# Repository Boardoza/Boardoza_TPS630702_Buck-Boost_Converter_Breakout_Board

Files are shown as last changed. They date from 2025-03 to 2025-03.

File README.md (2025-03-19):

# Boardoza TPS630702 Buck-Boost Regulator Module

The TPS630702 Buck-Boost Converter Breakout Board is an efficient, compact power management solution for applications requiring stable voltage output over a wide input voltage range. This module features automatic transition between step-down and boost mode, making it ideal for battery-powered projects. With high efficiency of up to 95%, adjustable output voltage selection, and multiple safety protections, it provides a reliable power supply for embedded systems, IoT devices, and other electronics requiring regulated power.

## [Click here to purchase!](https://www.ozdisan.com/maker-ve-iot-urunleri/boardoza/boardoza-modulleri/BOARDOZA-TPS630702/1206511)

|Front Side|Back Side|
|:---:|:---:|
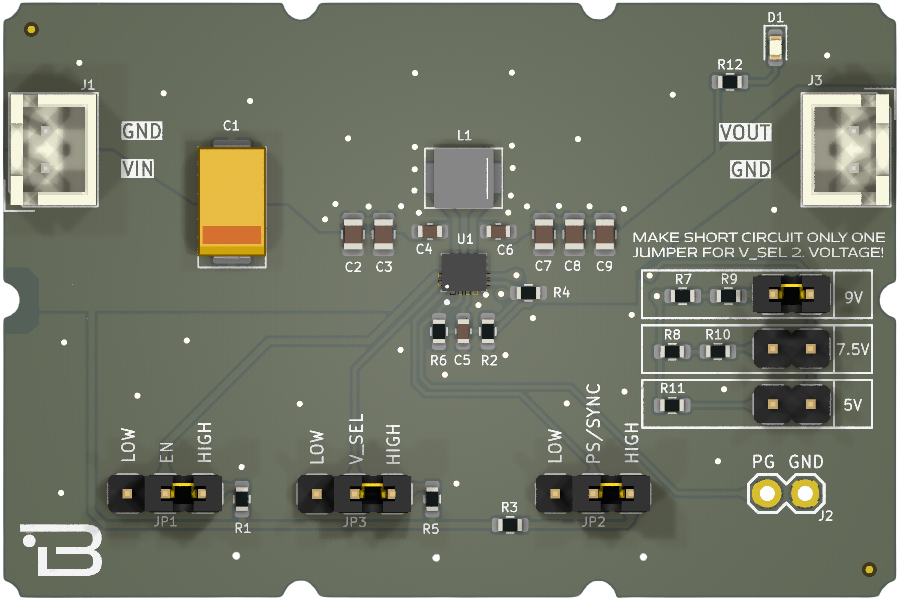
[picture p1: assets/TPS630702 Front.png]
Front
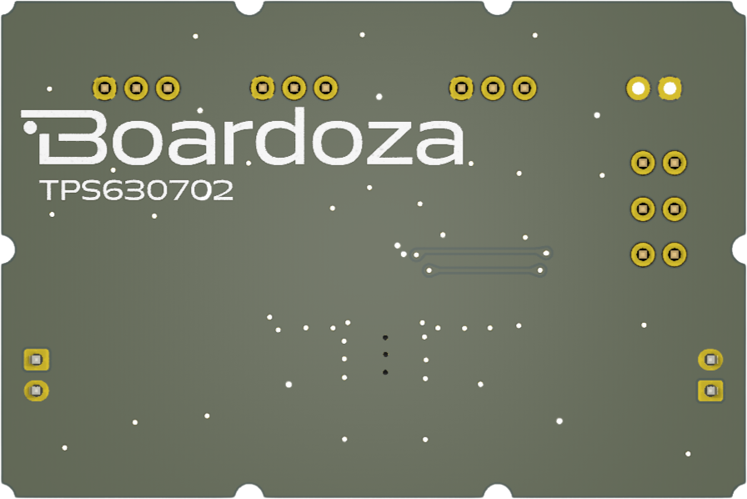
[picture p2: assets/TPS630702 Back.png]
Back
| | |

---

## Key Features

- **Wide Input Voltage Range**: Operates from 2.0V to 16V, suitable for battery and adapter applications.
- **Selectable Output Voltage**: Provides 3.3V by default, with options for 5V, 7.5V, and 9V via jumper selection.
- **High Current Capability**: Supports up to **2A output in both Buck and Boost modes**.
- **Automatic Buck-Boost Transition**: Seamlessly switches between step-down and boost mode depending on input voltage.
- **Load Disconnect & Output Discharge**: Ensures safety during shutdown.
- **Efficiency**: Up to 95%, reducing heat dissipation and improving battery life.
- **Protection Features**: Includes input/output overvoltage protection and undervoltage lockout.

---

## Technical Specifications

**Input Voltage:** 2.0V - 16V  

**Input Voltage Type:** Molex 2-pin 2.50mm header  

**Functions:** Buck-Boost Voltage Regulator  

**Output Voltage:** 3.3V, 5V, 7.5V, 9V (Selectable)  

**Output Current:**

- **Buck Mode:** 2A
- **Boost Mode:** 2A (VIN = 4V, VOUT = 5V)  

**Efficiency:** Up to **95%**  

**Operating Temperature:** -40°C ~ +150°C  

**Board Dimensions:** 40mm x 60mm  

---

## **Board Pinout**

### **J1 - Power Input Connector**

| Pin Number | Pin Name | Description |
|:---:|:---:|---|
| 1 | VIN | Voltage Input Pin (2V - 16V) |
| 2 | GND | Ground |

### **J2 - Power Good (PG) Indicator**

| Pin Number | Pin Name | Description |
|:---:|:---:|---|
| 1 | PG | Power Good signal, indicating output voltage status. |
| 2 | GND | Ground |

### **J3 - Output Connector**

| Pin Number | Pin Name | Description |
|:---:|:---:|---|
| 1 | VOUT | Adjustable Buck-Boost output (3.3V - 5V - 7.5V - 9V) |
| 2 | GND | Ground |

### **JP1 - Enable Control**

| Pin Number | Pin Name | Description |
|:---:|:---:|---|
| 1 | LOW | Connect to GND |
| 2 | EN | Regulator Enable Pin (Default: HIGH). Set LOW to disable the regulator. |
| 3 | HIGH | Connect to VIN |

### **JP2 - Power Save / Synchronization Mode**

| Pin Number | Pin Name | Description |
|:---:|:---:|---|
| 1 | LOW | Open drain power good output |
| 2 | PS/SYNC | Selects between forced PWM and power-save mode. Default: LOW (PWM Mode). |
| 3 | HIGH | Connect to VIN |

### **JP3 - Voltage Selection**

| Pin Number | Pin Name | Description |
|:---:|:---:|---|
| 1 | LOW | Open drain power good output |
| 2 | V_SEL | Voltage selection input (Default: LOW for 3.3V). Set HIGH to select another voltage. |
| 3 | HIGH | Connect to VIN |

### **Voltage Selection Pads**

| Pad | Description |
|:---:|---|
| 9V | Select 9V output by jumping this pad |
| 7.5V | Select 7.5V output by jumping this pad |
| 5V | Select 5V output by jumping this pad |

---

## Board Dimensions

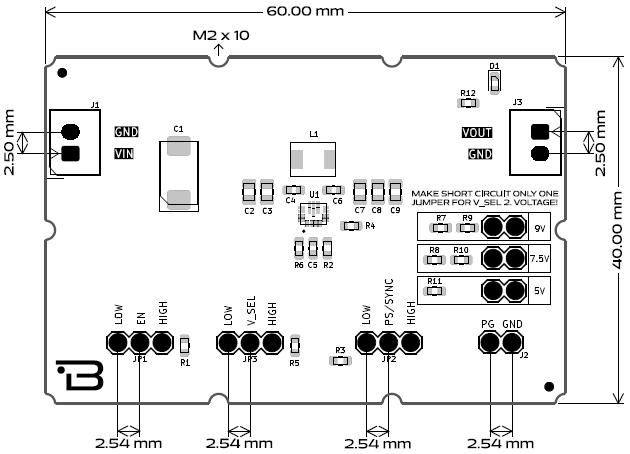
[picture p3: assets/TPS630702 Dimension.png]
Dimension


---

## Step Files

[Boardoza TPS63070.step](./assets/TPS630702%20Step.step)

---

## Datasheet

[Boardoza TPS63070 Datasheet.pdf](./assets/TPS630702%20Datasheet.pdf)

---

## Version History

- V1.0.0 - Initial Release

---

## Support

- If you have any questions or need support, please contact <support@boardoza.com>

---

## License

Shield: [][cc-by-sa]

This work is licensed under a [Creative Commons Attribution-ShareAlike 4.0 International License][cc-by-sa].

[][cc-by-sa]

[cc-by-sa]: http://creativecommons.org/licenses/by-sa/4.0/
[cc-by-sa-image]: https://licensebuttons.net/l/by-sa/4.0/88x31.png
[cc-by-sa-shield]: https://img.shields.io/badge/License-CC%20BY--SA%204.0-lightgrey.svg

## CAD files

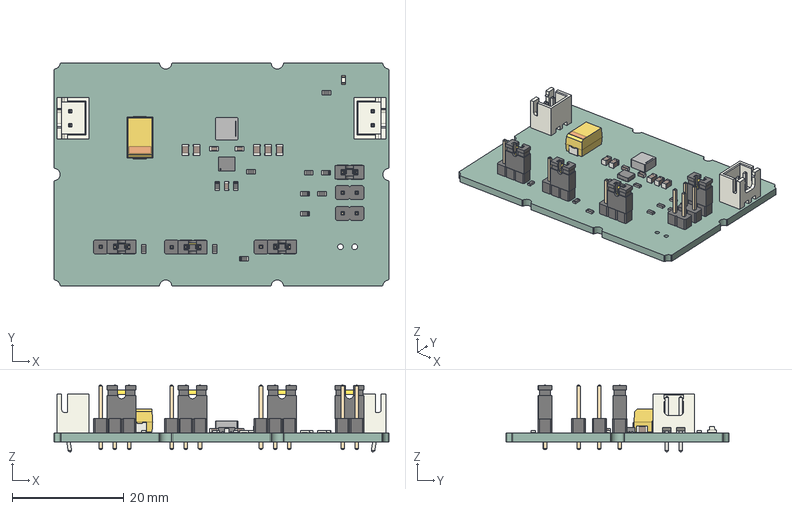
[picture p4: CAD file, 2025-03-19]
assets/TPS630702 Step.step
60.0 x 40.0 x 11.9 mm
PinHeader_1x03_P254mm_Vertical x 3
Jumper x 4
C_0603_1608Metric x 3
C_0805_2012Metric x 5
R_0603_1608Metric x 12
PinHeader_1x02_P254mm_Vertical x 3
CP_EIA_7343_43_Kemet_X
JST_B2B_XH_A x 2
RNR11
XFL4020-102MEC
LED_0603_1608Metric
_autosave-B-TPS630702-Brk-01Mbr-R01_PCB

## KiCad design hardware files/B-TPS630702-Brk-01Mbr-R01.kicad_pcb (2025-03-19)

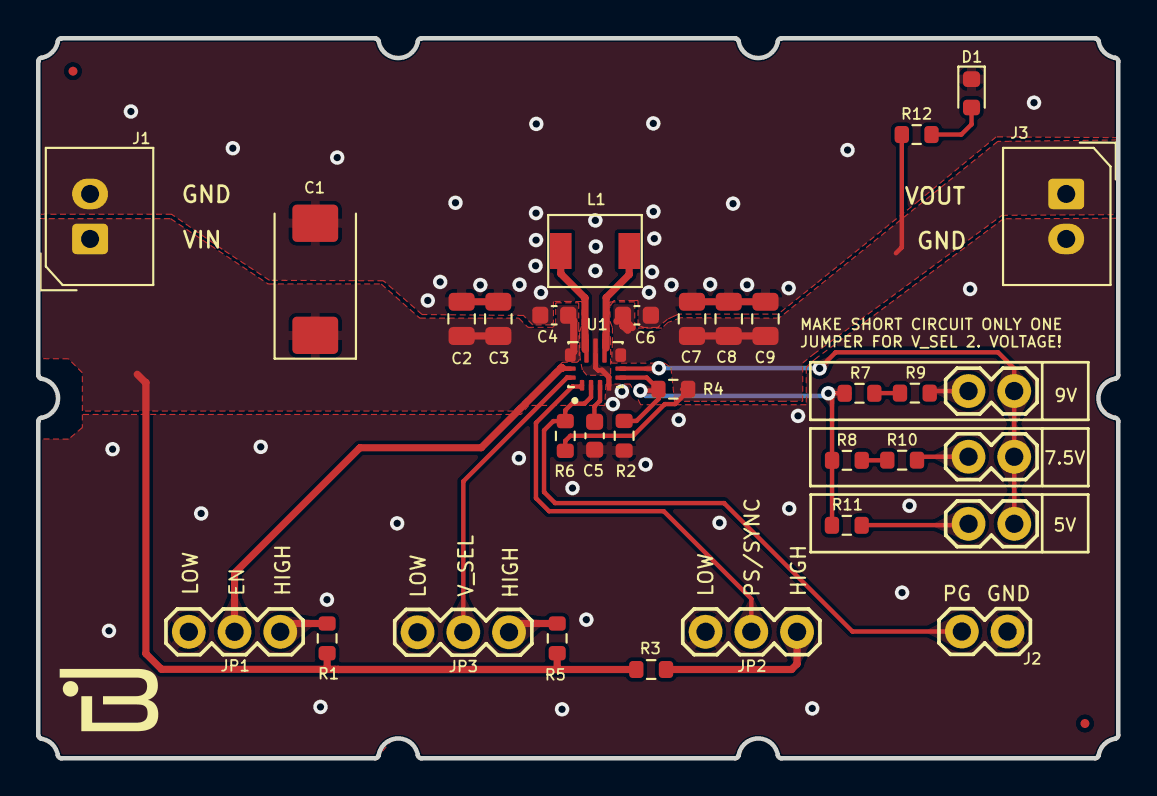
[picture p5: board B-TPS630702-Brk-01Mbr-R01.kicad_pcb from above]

Board: 2 copper layers, 60.0 x 40.0 mm, 33 parts (0 on the bottom side), 21 nets.

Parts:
C1: 68uF; CP_EIA-7343-43_Kemet-X
C2, C3: 10uF; C_0805_2012Metric
C4, C6: 10uF; C_0603_1608Metric
C5: 100nF; C_0603_1608Metric
C7, C8, C9: 22uF; C_0805_2012Metric
D1: LED POWER; LED_0603_1608Metric
J1, J3: 2317-02; 2317-02S_1x02_P2.50mm_Vertical
J2: PG; 1X02
JP1: EN; 1X03
JP2: PS/SYNC; 1X03
JP3: VSEL; 1X03
JP4: 9V; 1X02
JP5: 5V; 1X02
JP6: 7.5V; 1X02
L1: SMPI04020-1R5M; SMPI04020
R1, R3, R5, R12: 10K; R_0603_1608Metric
R2: 150K; R_0603_1608Metric
R4: 470K; R_0603_1608Metric
R6: 100K; R_0603_1608Metric
R7: 51K; R_0603_1608Metric
R8: 71.5K; R_0603_1608Metric
R9: 15K; R_0603_1608Metric
R10: 18K; R_0603_1608Metric
R11: 221K; R_0603_1608Metric
U1: TPS630702RNMR; TPS63070RNMT

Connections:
+3V3: C6.1, C7.1, C8.1, C9.1, J3.1, R4.2, R6.1, R12.1, U1.7_8 (VOUT)
EN: JP1.2, U1.14 (EN)
FB: R2.2, R4.1, R7.1, R8.1, R11.1, U1.5 (FB)
FB2: JP4.2, JP5.2, JP6.2, U1.6 (FB2)
GND: C1.2, C2.2, C3.2, C4.2, C5.2, C6.2, C7.2, C8.2, C9.2, D1.1 (K), J1.2, J2.2, J3.2, JP1.1, JP2.1, JP3.1, R2.1, U1.4 (GND), U1.10 (PGND)
unnamed: D1.2 (A), R12.2
unnamed: JP1.3, R1.2
unnamed: JP2.3, R3.1
unnamed: JP3.3, R5.2
unnamed: JP4.1, R9.2
unnamed: JP5.1, R11.2
unnamed: JP6.1, R10.2
unnamed: R7.2, R9.1
unnamed: R8.2, R10.1
unnamed: L1.2, U1.11 (L1)
unnamed: L1.1, U1.9 (L2)
unnamed: C5.1, U1.3 (VAUX)
PG: J2.1, R6.2, U1.2 (PG)
PS/SYNC: JP2.2, U1.1 (PS/SYNC)
V_IN: C1.1, C2.1, C3.1, C4.1, J1.1, R1.1, R3.2, R5.1, U1.12_13 (VIN)
V_SEL: JP3.2, U1.15 (VSEL)

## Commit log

2024-09-03 Initial release for TPS630702 breakout board.
    [TPS630702 Step.step]
2025-03-19 Update README for TPS630702 module and replace image assets
    [B-TPS630702-Brk-01Mbr-R01.kicad_pcb, B-TPS630702-Brk-01Mbr-R01.kicad_sch, TPS630702 Step.step]
